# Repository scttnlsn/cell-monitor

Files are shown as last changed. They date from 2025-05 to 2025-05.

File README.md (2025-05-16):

# cell-monitor

Battery cell monitor and balancer based on the AVR ATTiny85 MCU.

* reads cell voltage
* switches balancing FET
* communicates with a host controller via isolated serial
* low power consumption (<1mA when idle, ~2mA while active)

A cell monitor is intended to monitor a single cell as part of a larger series pack.
The cell monitor is powered directly from the cell it monitors and works with any chemistry
where the voltage remains within 1.8V-5.5V (i.e. lithium-ion, LiFePO4).

## Build

Dependencies:

* [pio](http://platformio.org)
* [make](https://www.gnu.org/software/make/)

```
make
make fuse
make flash
```

## Wiring

Cell monitors are wired in a daisy chain with the TX from the host controller connected to
the RX of cell monitor 1, the TX of cell monitor 1 connected to the RX of cell monitor 2, etc.
The TX of cell monitor N is connected to the RX of the host controller.

```
+-----------+
| HOST   RX | <------------------------------------------+
|        TX | >---+    +--->---+    +--->  ...  >---+    |
+-----------+     |    |       |    |               |    |
                  |    |       |    |               |    |
                +--------+   +--------+           +--------+
                | RX  TX |   | RX  TX |    ...    | RX  TX |
                |    1   |   |    2   |    ...    |    N   |
                +--------+   +--------+    ...    +--------+
```

Cell monitors are addressed by their position in the daisy chain.

## Serial protocol

The host controller initiates all communication with the network of cell monitors and does so at 9600 baud.
The host controller sends a request packet which is forwarded through the daisy chain to an addressed cell
monitor.  The addressed cell monitor will reply with a similar response packet which will be forwarded through
the remaining chain and eventually read by the host controller.

#### Packet structure

Communication consists of 5 byte packets with the following structure:

| Byte  | 7 | 6 | 5 | 4  | 3  | 2  | 1  | 0 |
| ----- | ----- | ----- | ----- | ----- | ----- | ----- | ----- | ----- |
| **1** | ID7 | ID6 | ID5 | ID4 | ID3 | ID2 | ID1 | ID0 |
| **1** | ADDR6 | ADDR5 | ADDR4 | ADDR3 | ADDR2 | ADDR1 | ADDR0 | REQ |
| **2** | REG6  | REG5  | REG4  | REG3  | REG2  | REG1  | REG0  | WRITE |
| **3** | VAL15 | VAL14 | VAL13 | VAL12 | VAL11 | VAL10 | VAL9  | VAL8  |
| **4** | VAL7  | VAL6  | VAL5  | VAL4  | VAL3  | VAL2  | VAL1  | VAL0  |
| **5** | CRC7  | CRC6  | CRC5  | CRC4  | CRC3  | CRC2  | CRC1  | CRC0  |

* **ID** - packet ID
* **ADDR6-0** - cell monitor address
* **REQ** - 1 if packet is a request, 0 if packet is a response
* **REG6-0** - register (described below)
* **WRITE** - 1 if packet is a write command, 0 if packet is a read command
* **VAL15-0** - value
* **CRC7-0** - CRC8 of prior 4 bytes

#### Registers

* `0x1` - cell address (1 byte, unsigned)
* `0x2` - cell voltage (2 bytes, unsigned)
* `0x3` - balance (1 if balancing, 0 otherwise)

#### Example

*Reading the voltage from cell 1*

Request:

| Byte | Value |
| ---- | --- |
| 1 | 00000001 |
| 2 | 00000011 |
| 3 | 00000110 |
| 4 | 00000000 |
| 5 | 00000000 |
| 6 | 00100101 |

* `ID` = 1
* `ADDR` = 1
* `REQ` bit set to 1
* `REG` = 3
* `WRITE` bit set to 0
* `VAL` is not applicable for read request
* `CRC` = crc8(4345692160)

The following response will be received:

| Byte | Value |
| ---- | --- |
| 1 | 00000001 |
| 1 | 00000010 |
| 2 | 00000110 |
| 3 | 00001100 |
| 4 | 11100100 |
| 5 | 01111101 |

* `ID` = 1
* `ADDR` = 1
* `REQ` bit set to 0
* `REG` = 3
* `WRITE` bit set to 0
* `VAL` is the returned voltage (3300mV in this example)
* `CRC` = crc8(4328918244)

#### Address assignment

A cell monitor has an undefined address when it is initially powered on.  The host controller
needs to initiate an address assignment request (which has slightly different semantics than
other value requests):

| Byte | Value |
| ---- | --- |
| 1 | 00000001 |
| 2 | 00000001 |
| 3 | 00000011 |
| 4 | 00000000 |
| 5 | 00000001 |
| 6 | 11001110 |

* `ID` = 1
* `ADDR` = 0 (broadcast to all cell monitors)
* `REQ` bit set to 1
* `REG` = 1
* `WRITE` bit set to 1
* `VAL` = first cell address
* `CRC` = crc8(4311941121)

The first cell monitor will receive the request and set its address to the value in the `VAL` field.
Instead of sending a response it will increment the `VAL` field and forward the request onward.
Eventually the host controller will receive the same request packet (with an incremented `VAL`).
The host controller should assert that `VAL` equals 1 more than the number of cell monitors in the
network.

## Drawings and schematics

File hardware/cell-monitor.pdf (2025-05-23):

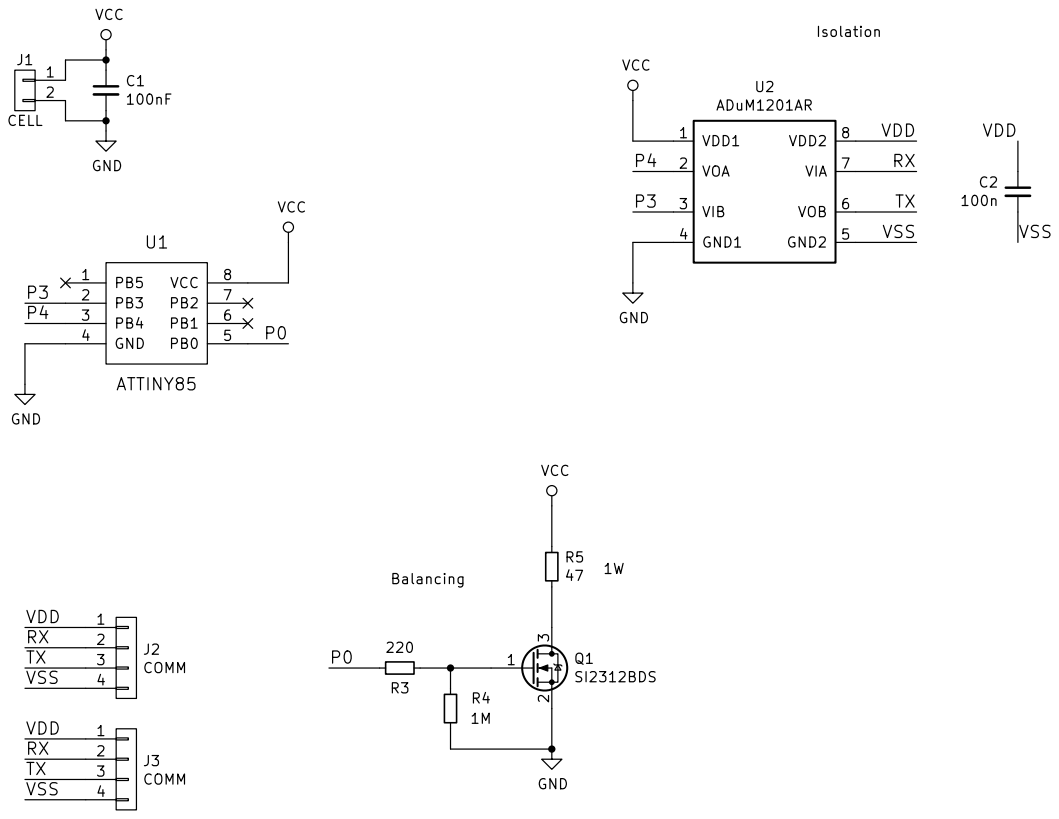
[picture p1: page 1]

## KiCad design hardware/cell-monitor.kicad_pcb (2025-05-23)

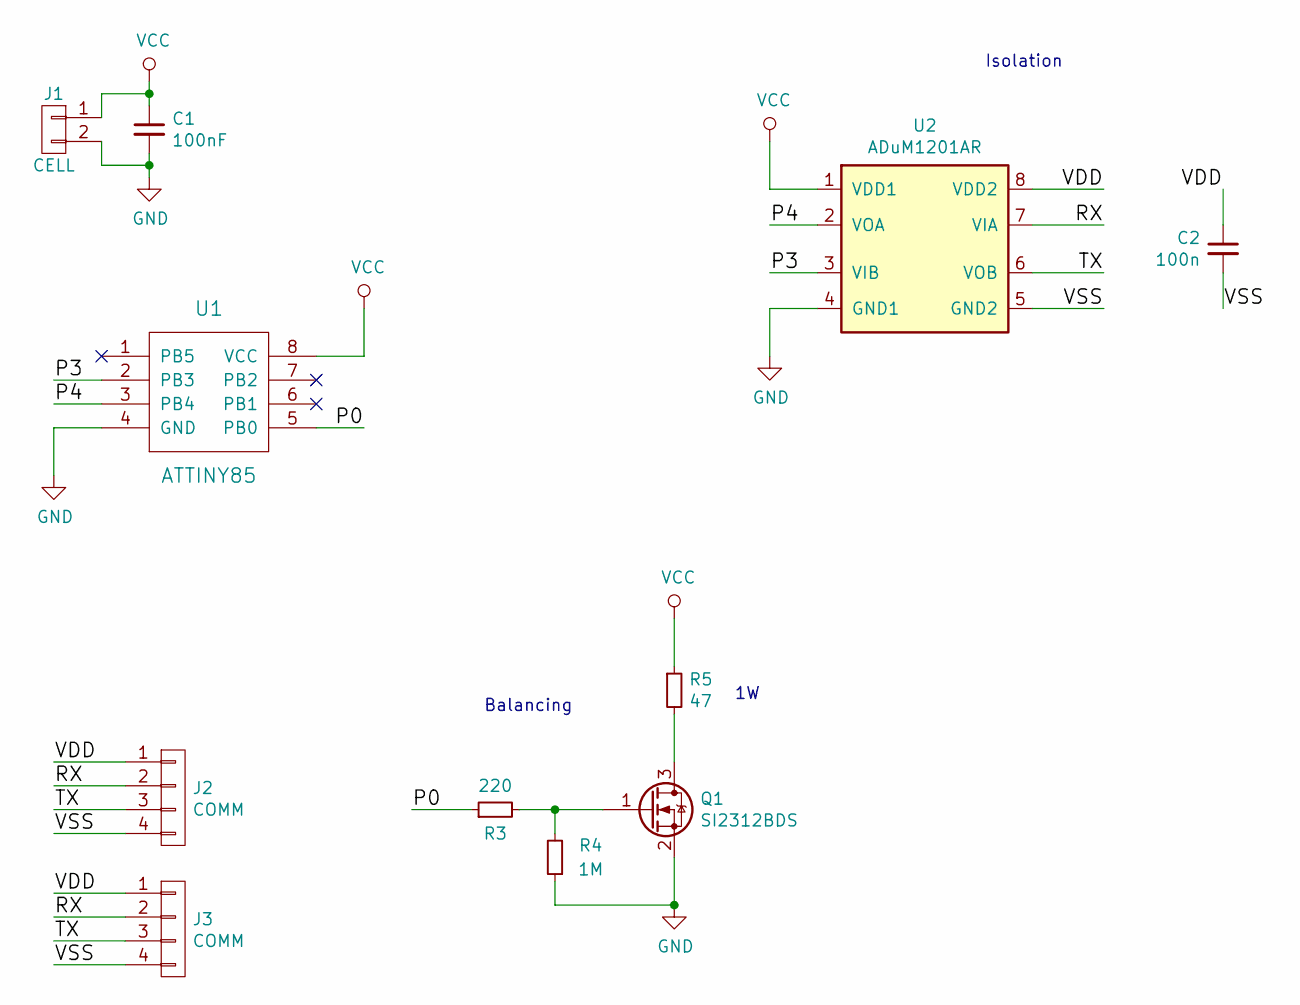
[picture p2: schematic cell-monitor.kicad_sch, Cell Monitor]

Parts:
C1: 100nF; C_1206_HandSoldering
C2: 100n; C_1206_HandSoldering
J1: CELL; bornier2
J2, J3: COMM; Pin_Header_Straight_1x04_Pitch2.54mm
Q1: SI2312BDS; SOT-23
R3: 220; R_1206_HandSoldering
R4: 1M; R_1206_HandSoldering
R5: 47; R_2512_HandSoldering
U1: ATTINY85; DIP-8_W7.62mm_Socket
U2: ADuM1201AR; SOIC-8_3.9x4.9mm_Pitch1.27mm

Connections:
/P0: R3.1, U1.5 (PB0)
/P3: U1.2 (PB3), U2.3 (VIB)
/P4: U1.3 (PB4), U2.2 (VOA)
/RX: J2.2, J3.2, U2.7 (VIA)
/TX: J2.3, J3.3, U2.6 (VOB)
/VDD: C2.1, J2.1, J3.1, U2.8 (VDD2)
/VSS: C2.2, J2.4, J3.4, U2.5 (GND2)
GND: C1.2, J1.2, Q1.2 (S), R4.1, U1.4 (GND), U2.4 (GND1)
unnamed: Q1.3 (D), R5.2
unnamed: Q1.1 (G), R3.2, R4.2
VCC: C1.1, J1.1, R5.1, U1.8 (VCC), U2.1 (VDD1)

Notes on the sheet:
Isolation
Balancing

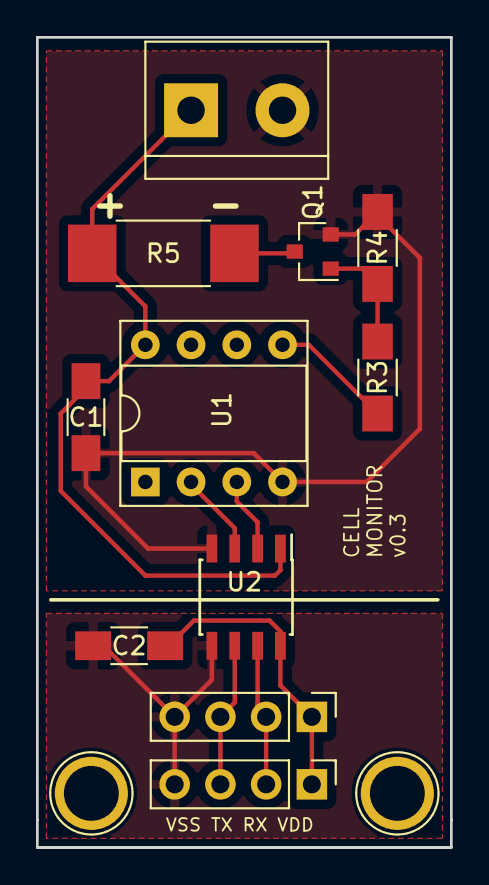
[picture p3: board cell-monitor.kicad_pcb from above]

Board: 2 copper layers, 23.0 x 45.0 mm, 11 parts (0 on the bottom side), 11 nets.

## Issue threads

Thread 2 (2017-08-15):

ATTiny85 oscillator calibration

scttnlsn, 2017-08-15:
I've noticed that I occasionally do not receive a response to the `SEND_VOLTAGE` command when issued.  Could be that the internal oscillator is not precise.  There's a register to calibrate the actual value.

scttnlsn, 2017-08-15:
Here's some good info about it: https://github.com/pepaslabs/CalibrateATtiny85OSCCAL

scttnlsn, 2018-06-09:
I believe the issue was due to my misuse of the internal 1mHz oscillator.  I don't think the bit-banged serial works at this speed.  Communication seems much more reliable when using the internal 8mHz oscillator.

Closed 2018-06-09.

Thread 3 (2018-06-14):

Voltage calibration not working

scttnlsn, 2018-06-14:
Removed the voltage calibration for now: https://github.com/scttnlsn/cell-monitor/commit/21d121bcfd4a57f2c269019b0e8e7706dea3398e

Was causing issues with the voltage readings for some reason.  Returned voltage values would slowly decrease to some fixed point below the actual voltage.  I was not sending any write requests to my knowledge.  Voltage can still be calibrated manually by writing the reference voltage value.

Jff011, 2018-09-04:
Hi Scott
I wonder if your problem with the voltage calibration is related to this: https://www.avrfreaks.net/forum/attiny-adc-using-internal-ref-measure-vcc-problem

scttnlsn, 2018-09-04:
@Jff011 Thanks for the link!  There's already a delay after selecting the reference voltage (https://github.com/scttnlsn/cell-monitor/blob/master/src/adc.cpp#L17).  Are you thinking that I need to discard some samples?  The thing is, the ADC readings all seem to work just fine (even after calibrating the internal voltage reference) so I don't think the issue involves any hardware subtleties.  I suspect the issue has something to do with my calculations (i.e. calculating the interval voltage reference given the VCC value).  I haven't invested much time in this yet since it's easy enough to calibrate the voltage reference instead of the VCC reading (calculating the voltage reference manually).  Let me know if you have any ideas.

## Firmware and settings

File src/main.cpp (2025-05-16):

#include <Arduino.h>
#include <SoftwareSerial.h>

#include <avr/sleep.h>
#include <avr/wdt.h>

#include "config.h"
#include "adc.h"
#include "balance.h"
#include "communication.h"
#include "protocol.h"

#define adc_disable() (ADCSRA &= ~(1 << ADEN))
#define adc_enable() (ADCSRA |=  (1 << ADEN))

SoftwareSerial serial(RX_PIN, TX_PIN);
Balancer balancer(BALANCE_PIN);
Communication comm(serial);
Protocol protocol(&comm);

void sleep() {
  adc_disable();
  wdt_reset();
  wdt_disable();

  set_sleep_mode(SLEEP_MODE_PWR_DOWN);
  sleep_enable();
  sei();
  sleep_cpu();

  // wake up
  sleep_disable();
  adc_enable();
  wdt_enable(WDTO_1S);
  wdt_reset();
}

void setup() {
  // 1 second watchdog
  wdt_enable(WDTO_1S);

  serial.begin(9600);

  adc::init();
}

void loop() {
  uint32_t now = millis();

  if (comm.update(now)) {
    uint8_t *data = comm.data();

    packet_t packet;
    if (protocol.handle(data, &packet)) {
      switch (packet.reg) {
        case REG_VOLTAGE:
          if (packet.write) {
            adc::calibrate_voltage(packet.value);
          }
          protocol.respond(&packet, adc::read_vcc());
          break;

        case REG_BALANCE:
          if (packet.write) {
            if (packet.value) {
              balancer.enable();
            } else {
              balancer.disable();
            }
          }
          protocol.respond(&packet, balancer.enabled());
          break;
      }
    }
  }

  wdt_reset();

  uint8_t balancing = balancer.update();
  if (!balancing && !serial.available() && comm.empty()) {
    sleep();
  }
}

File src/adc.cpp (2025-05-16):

#include <Arduino.h>
#include <avr/eeprom.h>

#include "adc.h"
#include "config.h"

// ATTiny internal voltage reference
#define BANDGAP_NOMINAL_VOLTAGE 1100L

// 4^(12bit - 10bit) = 16 samples
#define NUM_SAMPLES 16

// 10bit ADC w/ 2bit oversampling = 12bit
#define ADC_MAX 4095L

namespace adc {
  uint32_t _ref_voltage = BANDGAP_NOMINAL_VOLTAGE;

  // returns a single 10-bit reading of the bandgap voltage
  uint16_t read_bandgap() {
    // use VCC as reference
    // measure internal bandgap reference voltage
    ADMUX = _BV(MUX3) | _BV(MUX2);

    // wait for ADC to settle
    delay(2);

    // start conversion
    ADCSRA |= _BV(ADSC);

    // wait for conversion to complete
    while (bit_is_set(ADCSRA, ADSC));

    uint8_t low  = ADCL; // must read ADCL first
    uint8_t high = ADCH;
    return (high << 8) | low;
  }

  // returns an oversampled 12-bit reading of the bandgap voltage
  uint16_t sample_bandgap() {
    uint32_t sum = 0;
    for (uint16_t i = 0; i < NUM_SAMPLES; i++) {
      sum += read_bandgap();
    }

    // shift by 12bit - 10bit = 2bits
    uint16_t bandgap = sum >> 2;
    return bandgap;
  }

  void init() {
    _ref_voltage = eeprom_read_word((uint16_t *)0x0);
    if ((int) _ref_voltage == -1) {
      _ref_voltage = BANDGAP_NOMINAL_VOLTAGE;
    }
  }

  uint16_t ref_voltage() {
    return _ref_voltage;
  }

  void set_ref_voltage(uint16_t ref_voltage) {
    _ref_voltage = ref_voltage;
    eeprom_write_word((uint16_t *) 0x0, _ref_voltage);
  }

  void calibrate_voltage(uint16_t vcc_voltage) {
    uint32_t numerator = (uint32_t) vcc_voltage * (uint32_t) sample_bandgap();
    uint32_t ref_voltage = numerator / (uint32_t) ADC_MAX;
    set_ref_voltage((uint16_t) ref_voltage);
  }

  uint16_t read_vcc() {
    uint16_t bandgap = sample_bandgap();
    return ((uint32_t) _ref_voltage * ADC_MAX) / bandgap;
  }
}

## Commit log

2017-08-15 Make cell address and ref voltage configurable via env var
2017-08-15 Added schematic
2017-08-18 Added thermistor for cell temp monitoring
2017-08-18 Update schematic
2017-08-18 Added series gate resistor
2018-03-07 Added KiCad project with hardware schematic and PCB layout
    [cell-monitor.kicad_pcb, cell-monitor.sch]
2018-05-21 Initial work on new, daisy chained protocol
2018-06-09 Voltage calibration
2018-06-14 Remove voltage calibration for now
2025-05-16 Protocol update
    - remove temperature check (pack monitor can do this)
    - add `id` byte to packet
    - remove irrelevant registers
2025-05-23 Remove temp related hardware
    [cell-monitor.kicad_pcb, cell-monitor.kicad_sch]
2025-05-23 Clean up KiCad files
    [cell-monitor.kicad_pcb, cell-monitor.sch]
